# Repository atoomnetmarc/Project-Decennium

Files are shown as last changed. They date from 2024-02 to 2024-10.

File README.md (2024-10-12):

# Status

Assembled and working.

# Firmware

Flash the firmware: https://github.com/atoomnetmarc/Project-Decennium-Firmware

# Build

Order components mentioned on the [BOM](Kicad/bom/ibom.html). For the `Wemos D1 mini usb-c` (U1) you need 2 pieces of 1x08 right angle 2.54mm pin header.

Order PCB. You may want to check the option remove the order number from the front of the PCB.

Solder the PCB.

# 3d-print

3d-print a [stand](3d-print/Project-Decennium%20PCB%20stand.stl). Orient the print for printing like [this](3d-print/Project-Decennium%20PCB%20stand%20-%20print%20orientation%20example.png).

Use 2 M3x12 BHCS screws to screw the stand to the pcb.

# Pics

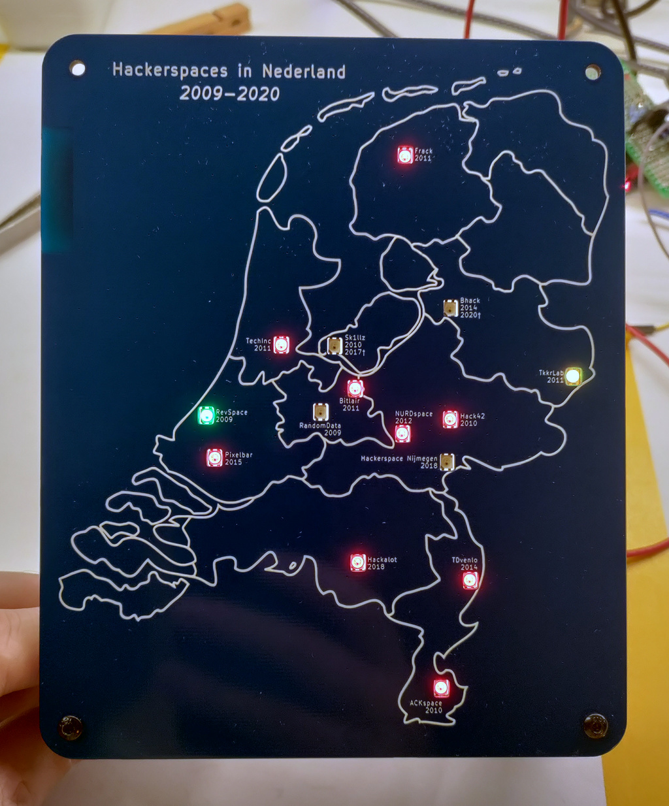
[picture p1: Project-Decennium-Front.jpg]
Front of PCB


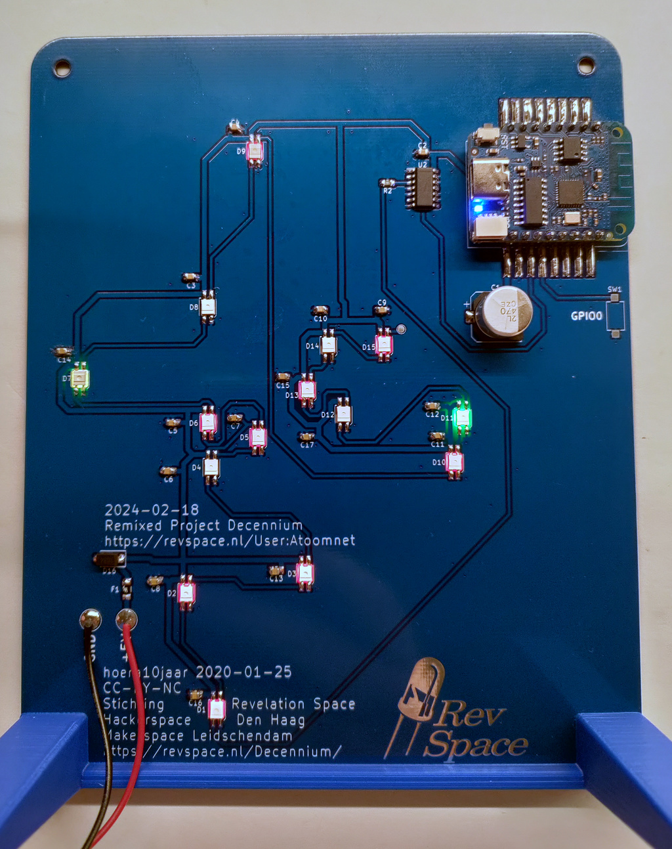
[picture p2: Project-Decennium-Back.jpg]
Back of PCB


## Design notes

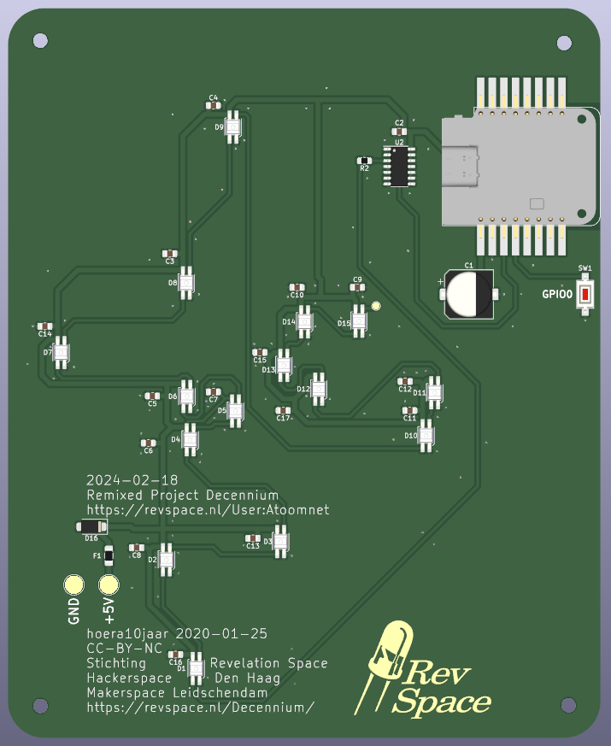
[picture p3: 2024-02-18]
Project-Decennium-Back.png

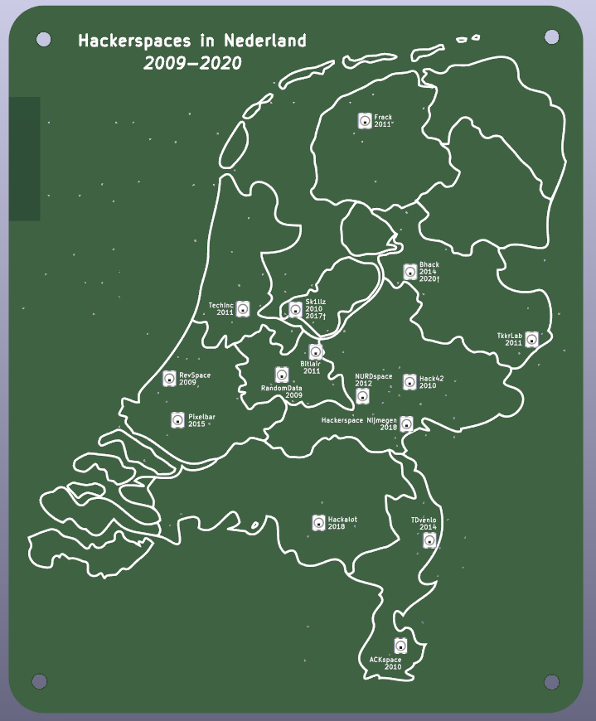
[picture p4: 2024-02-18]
Project-Decennium-Front.png

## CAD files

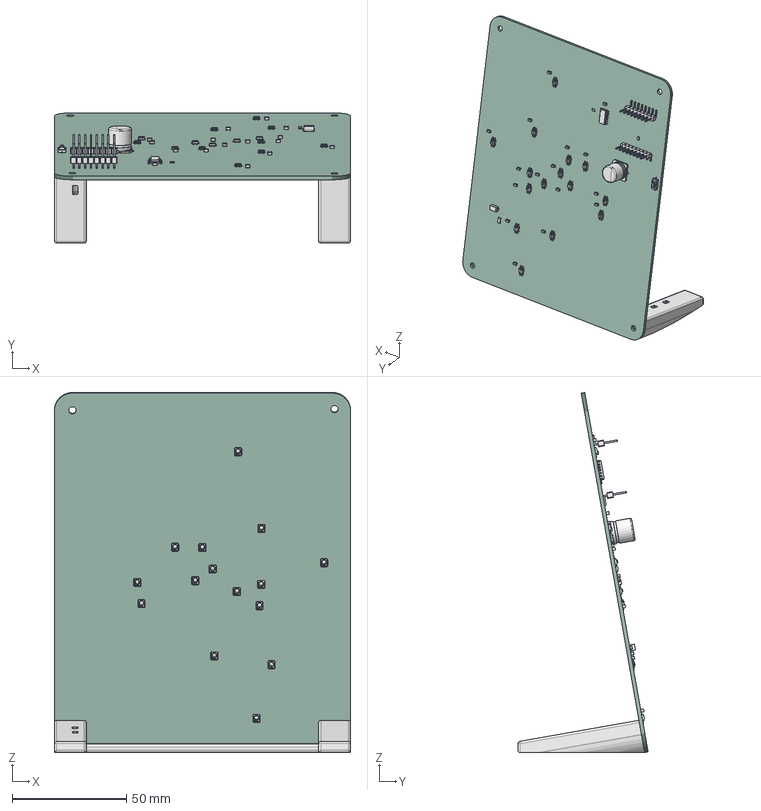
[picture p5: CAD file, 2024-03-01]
3d-print/Project-Decennium PCB stand.FCStd
129.5 x 57.0 x 157.4 mm
SK6812MINI-E v4
SK6812MINI-E v005
SK6812MINI-E v006
SK6812MINI-E v007
SK6812MINI-E v008
SK6812MINI-E v010
SK6812MINI-E v011
SK6812MINI-E v012
SK6812MINI-E v013
SK6812MINI-E v014
SK6812MINI-E v016
SK6812MINI-E v017
SK6812MINI-E v018
SK6812MINI-E v019
SK6812MINI-E v020
SK6812MINI-E v022
SK6812MINI-E v023
SK6812MINI-E v024
SK6812MINI-E v025
SK6812MINI-E v026
SK6812MINI-E v028
SK6812MINI-E v029
SK6812MINI-E v030
SK6812MINI-E v031
SK6812MINI-E v032
SK6812MINI-E v034
SK6812MINI-E v035
SK6812MINI-E v036
SK6812MINI-E v037
SK6812MINI-E v038
SK6812MINI-E v040
SK6812MINI-E v041
SK6812MINI-E v042
SK6812MINI-E v043
SK6812MINI-E v044
SK6812MINI-E v046
SK6812MINI-E v047
SK6812MINI-E v048
SK6812MINI-E v049
SK6812MINI-E v050
SK6812MINI-E v052
SK6812MINI-E v053
SK6812MINI-E v054
SK6812MINI-E v055
SK6812MINI-E v056
SK6812MINI-E v058
SK6812MINI-E v059
SK6812MINI-E v060
SK6812MINI-E v061
SK6812MINI-E v062
SK6812MINI-E v064
SK6812MINI-E v065
SK6812MINI-E v066
SK6812MINI-E v067
SK6812MINI-E v068
SK6812MINI-E v070
SK6812MINI-E v071
SK6812MINI-E v072
SK6812MINI-E v073
SK6812MINI-E v074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

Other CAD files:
3d-print/Project-Decennium PCB stand.stl

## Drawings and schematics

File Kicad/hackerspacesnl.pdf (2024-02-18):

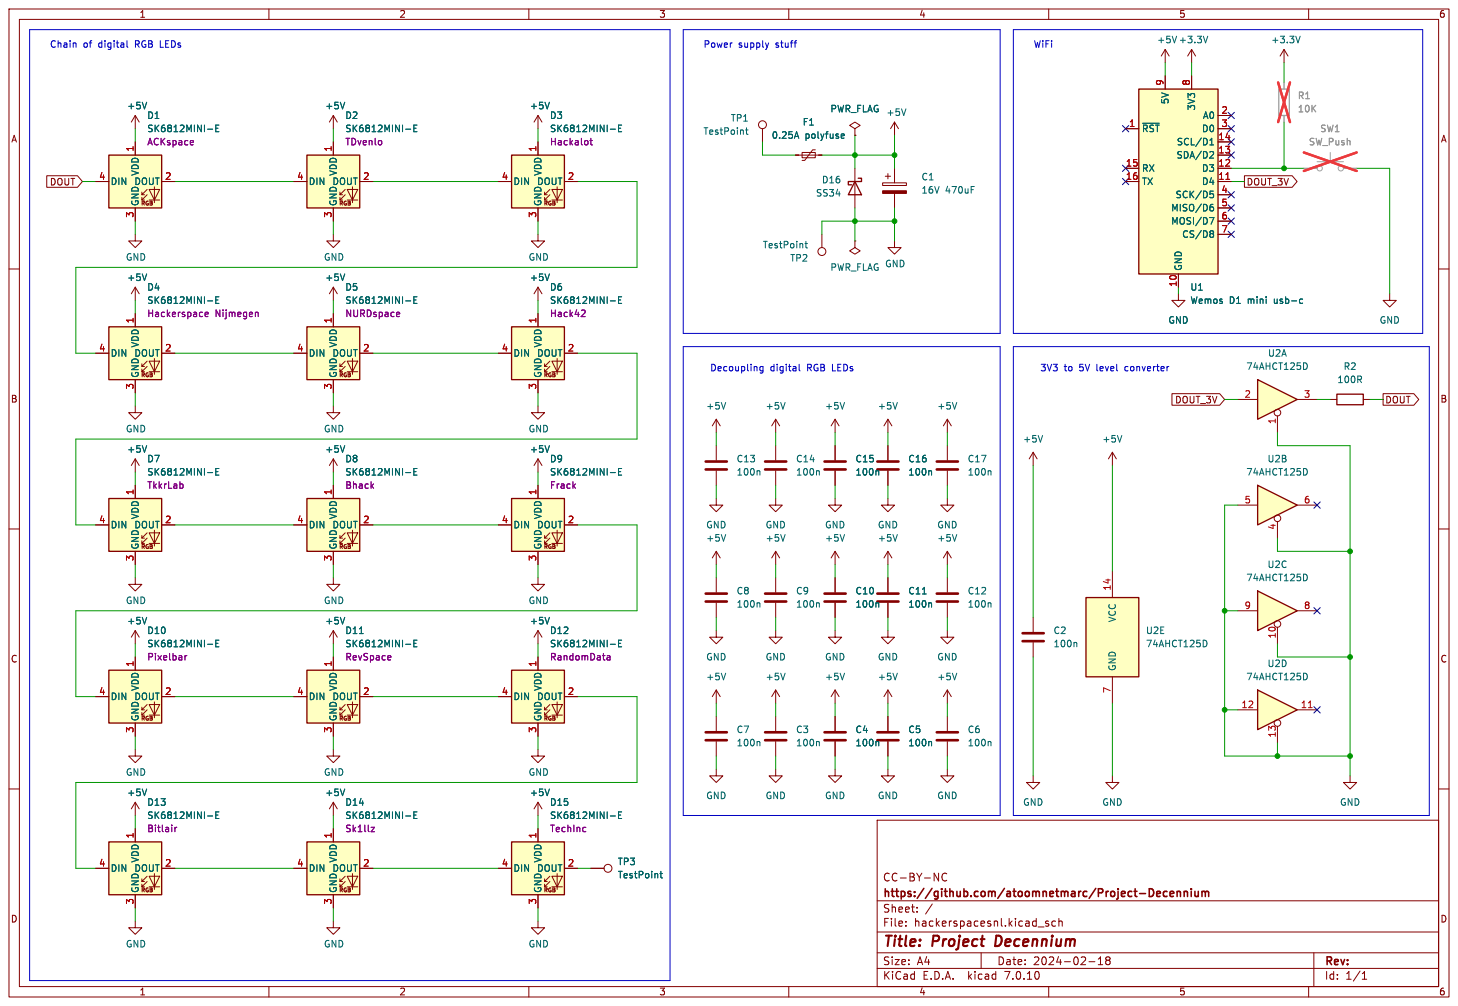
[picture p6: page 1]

9 U1 Wemos D1 mini usb-c GND

3 DIN 4 D4SK6812MINI-E Hackerspace Nijmegen VDD

PWR_FLAG GND TP2 TestPoint RGB VDD

3 DIN 4 D4SK6812MINI-E Hackerspace Nijmegen GND

3 DIN 4 TP3 TestPoint D12 SK6812MINI-E RandomData VDD

File: hackerspacesnl.kicad_sch Sheet: / https://github.com/atoomnetmarc/Project-Decennium

Id: 1/1 Title: Project Decennium

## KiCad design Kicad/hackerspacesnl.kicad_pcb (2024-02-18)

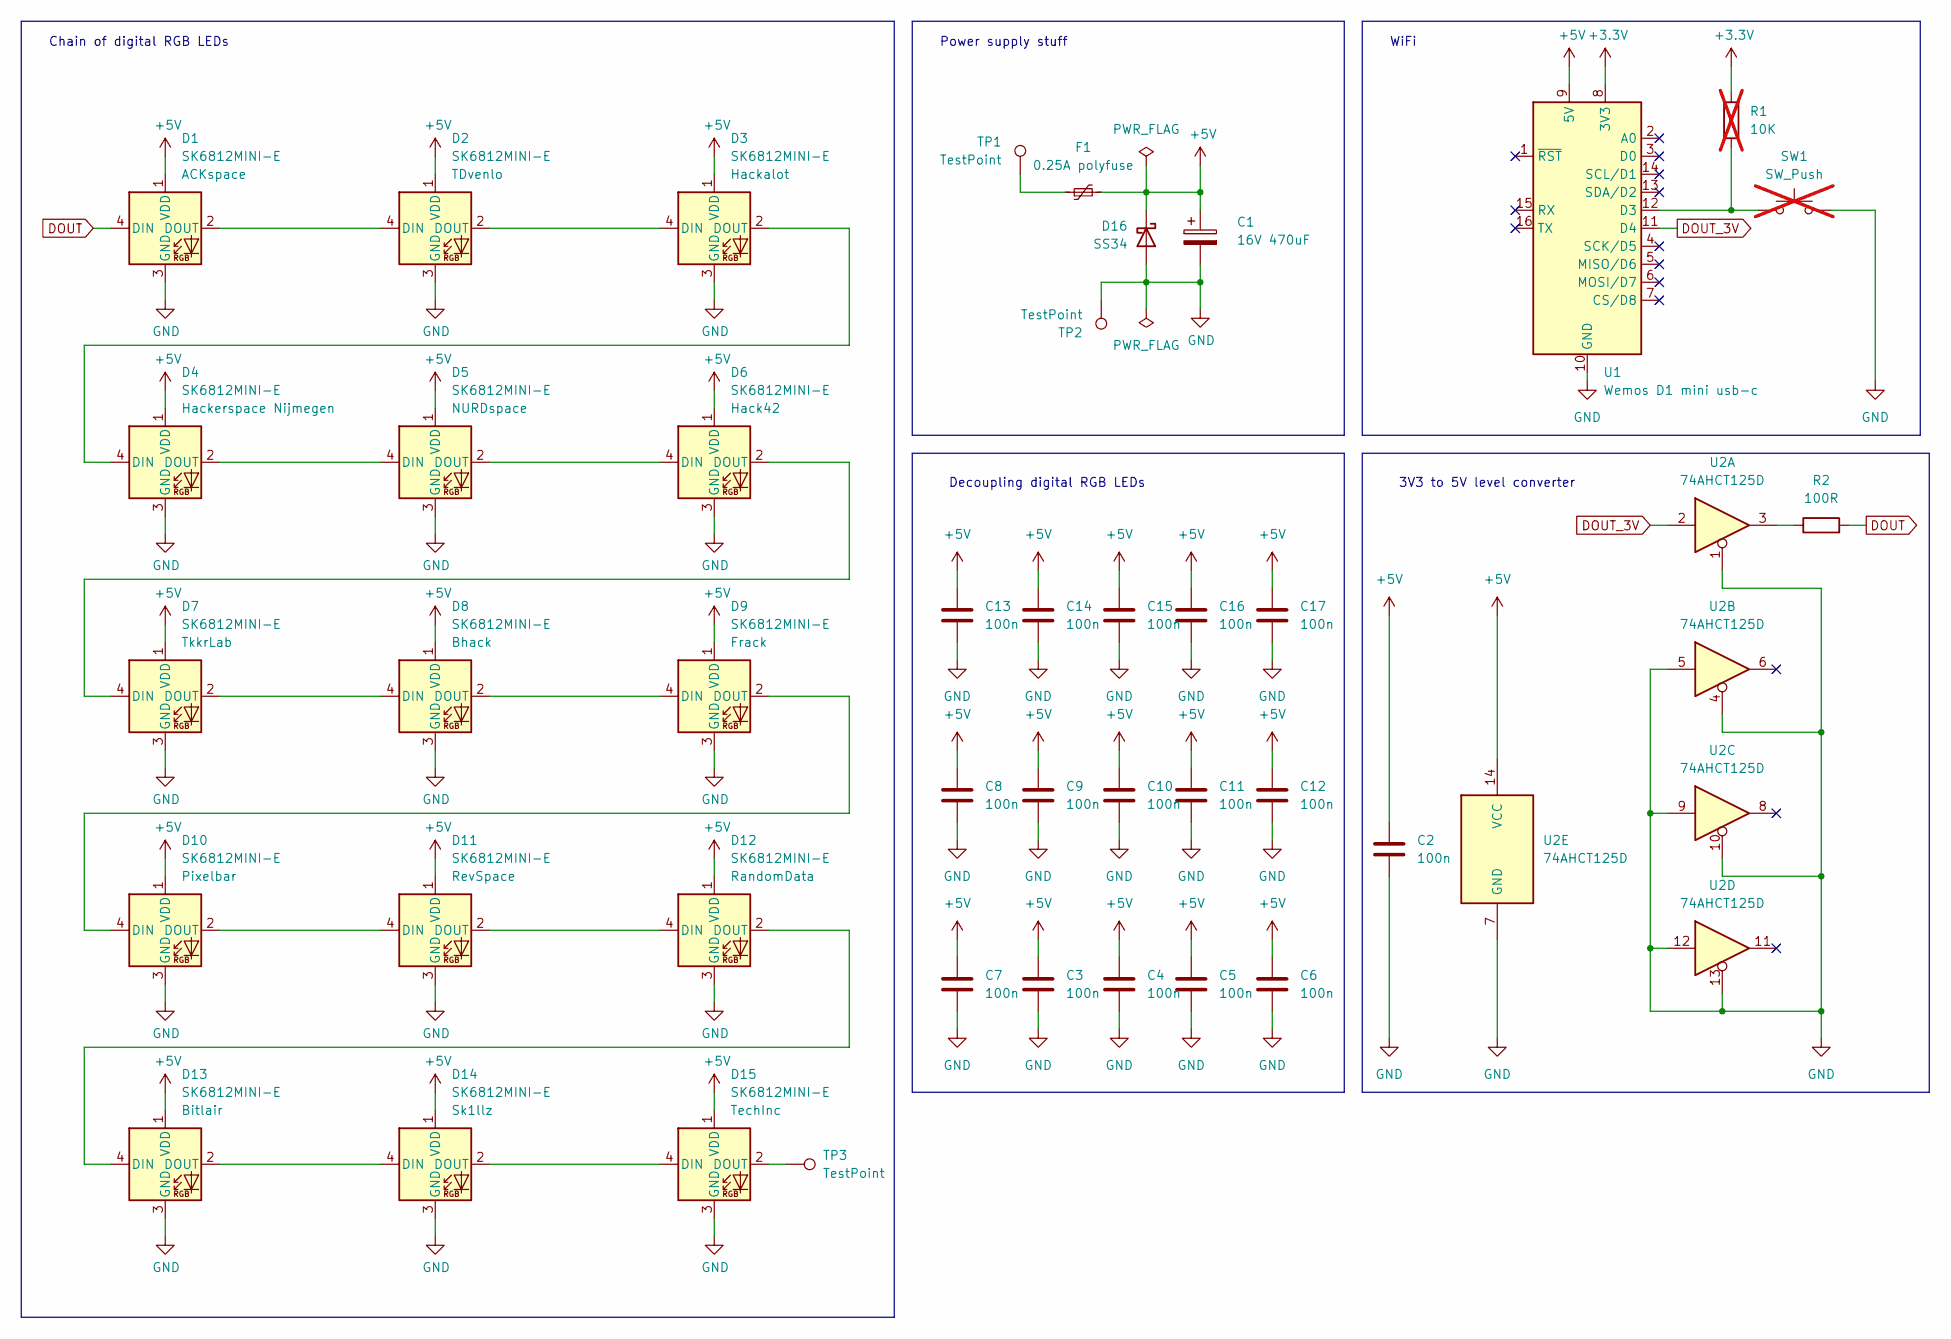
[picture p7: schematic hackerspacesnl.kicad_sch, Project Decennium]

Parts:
C1: 16V 470uF; CP_Elec_10x10.5
C2, C3, C4, C5, C6, C7, C8, C9, C10, C11, C12, C13, C14, C15, C16, C17: 100n; C_0805_2012Metric_Pad1.18x1.45mm_HandSolder
D1, D2, D3, D4, D5, D6, D7, D8, D9, D10, D11, D12, D13, D14, D15: SK6812MINI-E; LED_SK6812MINI-E_3.2x2.8x1.78mm_P1.5mm; LCSC C391863
D16: SS34; D_SMA
F1: 0.25A polyfuse; Fuse_1206_3216Metric_Pad1.42x1.75mm_HandSolder
R1: 10K; R_0805_2012Metric_Pad1.20x1.40mm_HandSolder; not fitted
R2: 100R; R_0805_2012Metric_Pad1.20x1.40mm_HandSolder
SW1: SW_Push; SW_SPST_CK_RS282G05A3; not fitted
TP1, TP2: TestPoint; TestPoint_Pad_D4.0mm
TP3: TestPoint; TestPoint_Pad_D1.5mm
U1: Wemos D1 mini usb-c; WEMOS_D1_mini_smt_hack
U2: 74AHCT125D; SOIC-14_3.9x8.7mm_P1.27mm

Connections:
+3.3V: R1.2, U1.8 (3V3)
+5V: C1.1, C2.1, C3.1, C4.1, C5.1, C6.1, C7.1, C8.1, C9.1, C10.1, C11.1, C12.1, C13.1, C14.1, C15.1, C16.1, C17.1, D1.1 (VDD), D2.1 (VDD), D3.1 (VDD), D4.1 (VDD), D5.1 (VDD), D6.1 (VDD), D7.1 (VDD), D8.1 (VDD), D9.1 (VDD), D10.1 (VDD), D11.1 (VDD), D12.1 (VDD), D13.1 (VDD), D14.1 (VDD), D15.1 (VDD), D16.1 (K), F1.2, U1.9 (5V), U2.14 (VCC)
DOUT: D1.4 (DIN), R2.2
DOUT_3V: U1.11 (D4), U2.2
GND: C1.2, C2.2, C3.2, C4.2, C5.2, C6.2, C7.2, C8.2, C9.2, C10.2, C11.2, C12.2, C13.2, C14.2, C15.2, C16.2, C17.2, D1.3 (GND), D2.3 (GND), D3.3 (GND), D4.3 (GND), D5.3 (GND), D6.3 (GND), D7.3 (GND), D8.3 (GND), D9.3 (GND), D10.3 (GND), D11.3 (GND), D12.3 (GND), D13.3 (GND), D14.3 (GND), D15.3 (GND), D16.2 (A), SW1.1, TP2.1, U1.10 (GND), U2.1, U2.4, U2.5, U2.7 (GND), U2.9, U2.10, U2.12, U2.13
unnamed: D1.2 (DOUT), D2.4 (DIN)
unnamed: D2.2 (DOUT), D3.4 (DIN)
unnamed: D3.2 (DOUT), D4.4 (DIN)
unnamed: D4.2 (DOUT), D5.4 (DIN)
unnamed: D5.2 (DOUT), D6.4 (DIN)
unnamed: D6.2 (DOUT), D7.4 (DIN)
unnamed: D7.2 (DOUT), D8.4 (DIN)
unnamed: D8.2 (DOUT), D9.4 (DIN)
unnamed: D9.2 (DOUT), D10.4 (DIN)
unnamed: D10.2 (DOUT), D11.4 (DIN)
unnamed: D11.2 (DOUT), D12.4 (DIN)
unnamed: D12.2 (DOUT), D13.4 (DIN)
unnamed: D13.2 (DOUT), D14.4 (DIN)
unnamed: D14.2 (DOUT), D15.4 (DIN)
unnamed: D15.2 (DOUT), TP3.1
unnamed: F1.1, TP1.1
unnamed: R2.1, U2.3
unnamed: R1.1, SW1.2, U1.12 (D3)

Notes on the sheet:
3V3 to 5V level converter
Power supply stuff
WiFi
Decoupling digital RGB LEDs
Chain of digital RGB LEDs

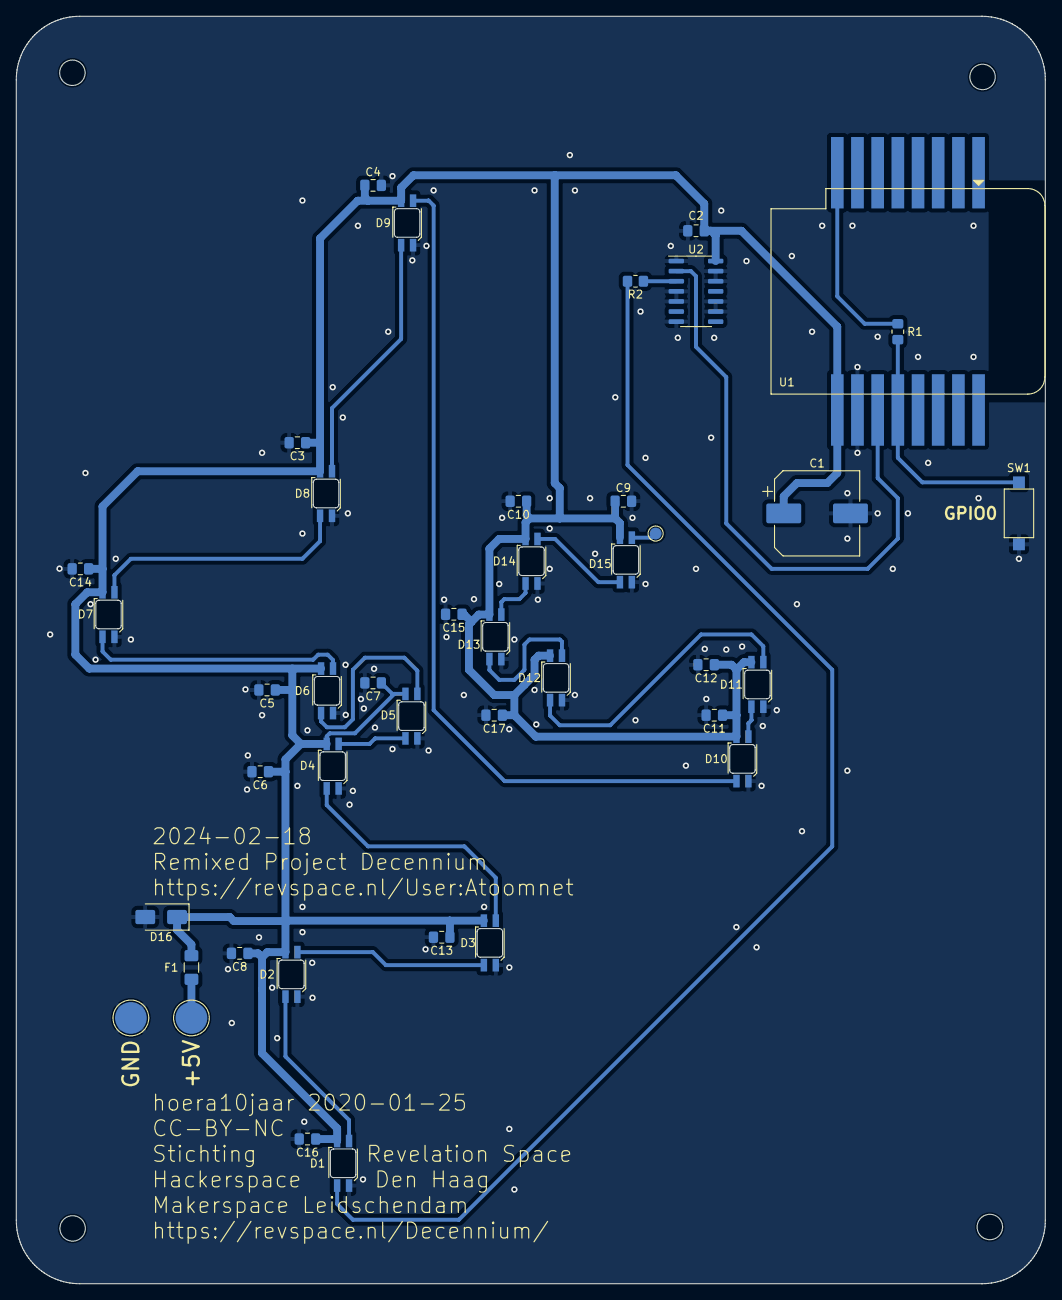
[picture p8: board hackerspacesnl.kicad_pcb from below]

Board: 2 copper layers, 129.5 x 159.5 mm, 44 parts (43 on the bottom side), 23 nets.

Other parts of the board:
Ref**: Val**; hsnl
Ref**#2: Val**; revspace_logo

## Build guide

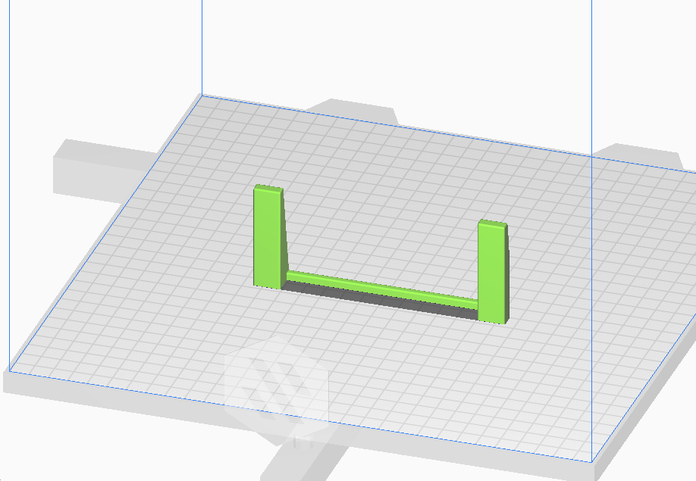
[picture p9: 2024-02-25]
3d-print/Project-Decennium PCB stand - print orientation example.png

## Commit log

2019-12-20 add values, connect matrix
    [hackerspacesnl.sch]
2019-12-20 schema compleet
    [hackerspacesnl.sch]
2019-12-20 art silk and board outline
    [hackerspacesnl.kicad_pcb]
2019-12-21 schemafoutje gefixt en eerste pcb stapjes
    [hackerspacesnl.sch]
2019-12-21 led footprint
    [hackerspacesnl.kicad_pcb, hackerspacesnl.sch]
2019-12-21 board outline
    [hackerspacesnl.kicad_pcb]
2019-12-21 fixed LED symbol, began initial layout
    [hackerspacesnl.kicad_pcb, hackerspacesnl.sch]
2019-12-21 wat moves
    [hackerspacesnl.kicad_pcb]
2019-12-21 sorted ratsnest, removed map as we will go bigger
    [hackerspacesnl.kicad_pcb, hackerspacesnl.sch]
2019-12-22 nieuwe svg voor hsnl
    [hackerspacesnl.kicad_pcb]
2019-12-22 bezig met nieuwe kaart, leds geplaatst en test van traces
    [hackerspacesnl.kicad_pcb]
2019-12-22 halverwege component plaatsing
    [hackerspacesnl.kicad_pcb, hackerspacesnl.sch]
2019-12-22 update multicolor led pads
2019-12-23 layout almost done
    [hackerspacesnl.kicad_pcb, hackerspacesnl.sch]
2019-12-23 back silk text and holes added
    [hackerspacesnl.kicad_pcb]
2019-12-23 klaar op refs na
    [hackerspacesnl.kicad_pcb]
2019-12-23 production files
    [hackerspacesnl-B_Cu.gbl, hackerspacesnl-B_Mask.gbs, hackerspacesnl-B_Paste.gbp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]
2019-12-23 wrong capacitor in BOM
    [hackerspacesnl_bom_clean.xls]
2019-12-23 fixed hsnl map footprint from uglies and generated new gerbers
    [hackerspacesnl-B_Cu.gbl, hackerspacesnl-B_Mask.gbs, hackerspacesnl-B_Paste.gbp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]
2019-12-23 silkscreen and new gerbers
    [hackerspacesnl-B_Cu.gbl, hackerspacesnl-B_Mask.gbs, hackerspacesnl-B_Paste.gbp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]
2019-12-23 versie zoals besteld
    [hackerspacesnl-B_Cu.gbl, hackerspacesnl-B_Mask.gbs, hackerspacesnl-B_Paste.gbp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]
2019-12-24 corrected POS excel document, added JLCpcb renders of P&P
    [hackerspacesnl-top-pos_gold_corrected.xlsx]
2020-01-04 nieuwe rev
    [hackerspacesnl-B_Cu.gbl, hackerspacesnl-B_Mask.gbs, hackerspacesnl-B_Paste.gbp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]
2024-02-18 Remix design. Use Wemos D1 mini and SK6812 instead of ESP32 with RG-led matrix.
    [campplanner.xlsx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]
2024-02-18 Case correct.
2024-02-25 Add 3d-printable stand.
    [Project-Decennium PCB stand.FCStd, Project-Decennium PCB stand.stl]
2024-02-29 Add photos off assembled PCB.
2024-03-01 Add 2 ty-rap holes.
    [Project-Decennium PCB stand.FCStd, Project-Decennium PCB stand.stl]

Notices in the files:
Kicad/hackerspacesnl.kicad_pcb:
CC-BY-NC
